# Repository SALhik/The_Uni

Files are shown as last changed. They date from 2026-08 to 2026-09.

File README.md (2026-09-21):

# The Uni Board
The uni-body split ortholinear keyboard for stenography, or the Uni for short. By Peter C Park. I used KiCad Nightly Release so the KiCad files are incompatible with older versions.

Buy it now at [StenoKeyboards.com](https://www.stenokeyboards.com/).

> **This checkout is a modified copy, not the upstream board.** The Pro Micro
> daughterboard has been replaced with an RP2040 module (Adafruit KB2040), which
> also moves the board to native USB-C. See
> [About this modification](#about-this-modification) for what changed, what was
> verified, and what was not. It is not affiliated with or endorsed by
> StenoKeyboards, and it is not any official Uni revision.

pcb
layout

## Product
If you are going DIY with this, here are the materials you need:
* The Uni PCB x 1 (diodes will come pre-assembled)
* Adafruit KB2040 x 1
* Switches x 28
* Keycaps x 28
* Willingness to solder x 1

If you want me to assemble here are the materials you need:
* money

## Microcontroller
This copy of the board is built around the **Adafruit KB2040** — an RP2040 module
in the Pro Micro form factor (33.02 x 17.78 mm) with 8 MB of QSPI flash and a
native USB-C connector.

Any module with the same 24-pin, 2.54 mm, 15.24 mm-row through-hole pattern will
physically fit, including the original Pro Micro and the Elite-C. **But the pin
functions are not interchangeable** — the schematic and silkscreen now name
RP2040 GPIOs, and pad 21 is treated as a 3.3 V regulator output rather than a
5 V rail. If you populate an AVR Pro Micro instead, the matrix still works
electrically, but use the original firmware pin names (see the table below).

## Switches
Nearly any switch is compatible with the v2. The board has a footprint that accomodates for mx, alps, and choc v1 style switches.

## Keycaps
The best keycaps to use are the OEM R3 keycaps with one of the rows inverted to reduce the gap in the middle.
I used to recommend 3d printing your caps but OEM R3 caps are better. There are other flat keycaps for mx style switches at pimpmykeyboard.com called f10 keycaps. There is also a slightly less flatter version called the G20 keycaps on their store and people have used them for steno.


## Soldering
All you have to solder are the switches and the KB2040 if you get the pcb with the diodes assembled. If not you'll have to solder the smd diodes yourself. Check the BOM file for the necessary materials.

The KB2040 mounts through-hole, in the same 24 holes the Pro Micro used. It
cannot be surface-mounted on this board — see [Castellated pads](#castellated-pads)
below.

`jlcpcb/assembly/` covers only the parts JLCPCB machine-assembles: the 28 SOD-123
diodes and the reset switch. The MCU module has never been listed there and still
isn't — you supply and solder it yourself, exactly as with the Pro Micro.

## About this modification

An independent modification of the upstream v2 hardware, moving it toward the
capabilities publicly described for later revisions. It was implemented from
scratch against public sources — Adafruit's own KB2040 design files for the
module, and the existing v2 KiCad files for everything else. No proprietary or
unreleased StenoKeyboards design files were used, referenced, or copied.

### What changed

| Area | Before | After |
| --- | --- | --- |
| MCU | Pro Micro (ATmega32U4) | Adafruit KB2040 (RP2040, 8 MB flash) |
| USB | micro-B | native USB-C |
| Logic rail | `+5V` | `+3V3` |
| Symbol | `keebio:ProMicro` | `uni-symbols:KB2040` |
| Footprint | `Keebio-Parts:ArduinoProMicro` | `uni-footprints:Adafruit_KB2040` |

Deliberately **unchanged**: key layout, switch matrix, diode topology, board
outline, mounting holes, and the MX/Alps/Choc hybrid switch footprint that gives
the board its spring-swap compatibility. The 24 through-hole pads keep their
exact original coordinates and drill sizes, and every *matrix* net keeps its pad
assignment, so no track was rerouted. One net name did change: the logic rail on
pad 21, `+5V` -> `+3V3`, per the table above. That rename is the only net-name
difference in the design, and the connectivity comparison normalises it. This
was verified by exporting the netlist before and after: 50 nets and 138 nodes in
both, with an identical connectivity graph.

### GPIO map

Every matrix net kept its physical pad, so this table is purely a renaming. The
"Pro Micro" column is the AVR pin the upstream QMK `config.h` refers to.

| Net | Pad | Pro Micro | KB2040 |
| --- | --- | --- | --- |
| `row0` | 20 | F4 | GP29 |
| `row1` | 14 | B2 | GP19 |
| `row2` | 13 | B6 | GP10 |
| `col0` | 19 | F5 | GP28 |
| `col1` | 18 | F6 | GP27 |
| `col2` | 17 | F7 | GP26 |
| `col3` | 16 | B1 | GP18 |
| `col4` | 15 | B3 | GP20 |
| `col5` | 12 | B5 | GP9 |
| `col6` | 11 | B4 | GP8 |
| `col7` | 10 | E6 | GP7 |
| `col8` | 9 | D7 | GP6 |
| `col9` | 8 | C6 | GP5 |
| `col10` | 7 | D4 | GP4 |

Matrix is 3 rows x 11 columns, `COL2ROW`, 28 keys. Pads 1, 2, 5 and 6 (GP0,
GP1, GP2, GP3) are unused, as they were on the Pro Micro. Pad 24 (`RAW`) is
unconnected; the KB2040 self-powers from USB through its own diode and
regulator.

**The firmware in `Firmware/` has not been ported** and still targets the
ATmega32U4. Adapting it is separate work.

### Silkscreen

The GPIO labels on the back are bare numbers (`4`, `29`) rather than `GP4`
style. The pads are on a 2.54 mm pitch and this board's setup enforces a 0.8 mm
minimum text height, at which four characters do not fit between adjacent pads.

### Castellated pads

The KB2040 has castellated edge pads for reflow mounting; **they are not placed
on this board, and the module must be through-hole soldered.** That is a layout
result rather than an assumption, but it comes from a PCB-layout and DRC
experiment in `unisplit_orthosteno.kicad_pcb`, not from a built board.
Castellated pads were added to the U1 footprint and shrunk down to 1.0 x 1.0 mm,
and at every size tried KiCad's DRC reported 10 net-to-net copper shorts against
the existing B.Cu matrix tracks, which already run through the channel where the
castellations would land — each castellation lands on top of its neighbour's
track. Nothing about solderability or reflow assembly was checked on hardware.
Fitting the castellations would require rerouting the matrix.

### Case and plate

The switch plate (`Case/switchplate/`) needed **no change**: switches are on
`F.Cu` and the module is on `B.Cu`, so they are on opposite faces, and the
module lands in a keyless channel that overlaps no cutout. Its 28 cutouts were
re-derived from the PCB switch coordinates and match exactly, at 14.00 x
14.00 mm. The back plate is likewise unchanged and still fully encloses the
module — the KB2040's onboard RESET and BOOT buttons are not externally
accessible, the same situation as the v2's own reset switch.

**The USB-C connector is wider than the micro-B it replaces.** Measured from
Adafruit's board file:

| | micro-B | USB-C | Delta |
| --- | --- | --- | --- |
| Connector width | 7.370 mm | 8.940 mm | +1.570 (about +0.79 per side) |
| Face inset from board edge | 0.145 mm | 0.462 mm | +0.317 deeper |

On the width alone this does **not** require a case change. The bezel in
`Case/3dp-full-case/full-case-bezels.kicad_pcb` already has a 17.462 mm notch in
its top edge (x 133.350 to 150.812), centred at x 142.081 — the module centre —
so an 8.940 mm connector clears it by about 4.26 mm a side. Only the width was
checked. The opening's height, whether a plug's overmold clears the recessed
board edge, and the printed `.stl` / `.FCStd` models were not measured.

### Fabrication outputs

`jlcpcb/gerber/` and `schematic.pdf` have been re-exported from the modified
design. The originals were plotted with KiCad 6.0.0 in 2022 and these with
KiCad 10.0.5, so the newer plotter re-renders mask and silkscreen and the file
diff is much larger than the design change. To separate the two, the *upstream*
board was exported with the same tool and settings and diffed against the new
export. Everything below is that comparison, not a claim about the raw diff:

| Layer | Change attributable to this modification |
| --- | --- |
| F.Cu, B.Cu | **no geometry change** — 40 differing lines per layer, all X2 netlist attributes: 38 `%TO.P%` pad names plus the 2 `%TO.N%` lines carrying the `+5V` -> `+3V3` rail rename; zero geometry ops |
| PTH, NPTH drill | **none** — 212 and 168 holes, byte-identical |
| Edge.Cuts | **none** — 24 ops, identical |
| F.Mask, B.Mask | **none** |
| F.Silkscreen, B.Silkscreen | changed, and confined to a 17.780 x 33.020 mm window — exactly the module outline |

`jlcpcb/assembly/` was deliberately **not** regenerated. No footprint moved (59
before, 59 after, zero position or rotation changes), and neither the BOM nor
the position file ever listed the MCU — they cover only the parts JLCPCB
machine-assembles.

The plate and back plate exports (`Case/switchplate/*/*.dxf`,
`Case/backplate/Gerbers/`) are also unchanged, because neither of those boards
was modified.

### Not verified

Stated so you know where to double-check rather than trust this document:

* **No physical build has been made.** Everything here is from file analysis.
* **No component heights were confirmed.** KB2040 PCB thickness, USB-C
  receptacle height, and whether a USB-C plug's overmold clears the recessed
  board edge are all unknown here. Later revisions are *reported* to use 5 mm
  screws and 9 mm standoffs against v2/v3's 4 mm and 4 mm; that figure is
  repeated here as hearsay and was **not** derived from these files. Confirm
  against the real parts before ordering hardware.
* **Nothing has been test-fabricated.** The gerbers are regenerated and were
  checked against a same-tool export of the upstream board, but no board house
  has run them and no panel has been built from them.
* **The exports come from a newer KiCad than the design file.** The board is
  still in KiCad 6 format and was plotted with KiCad 10.0.5. That is normal and
  the geometry was verified, but if you have KiCad 6 to hand, re-plotting there
  would keep the toolchain consistent.

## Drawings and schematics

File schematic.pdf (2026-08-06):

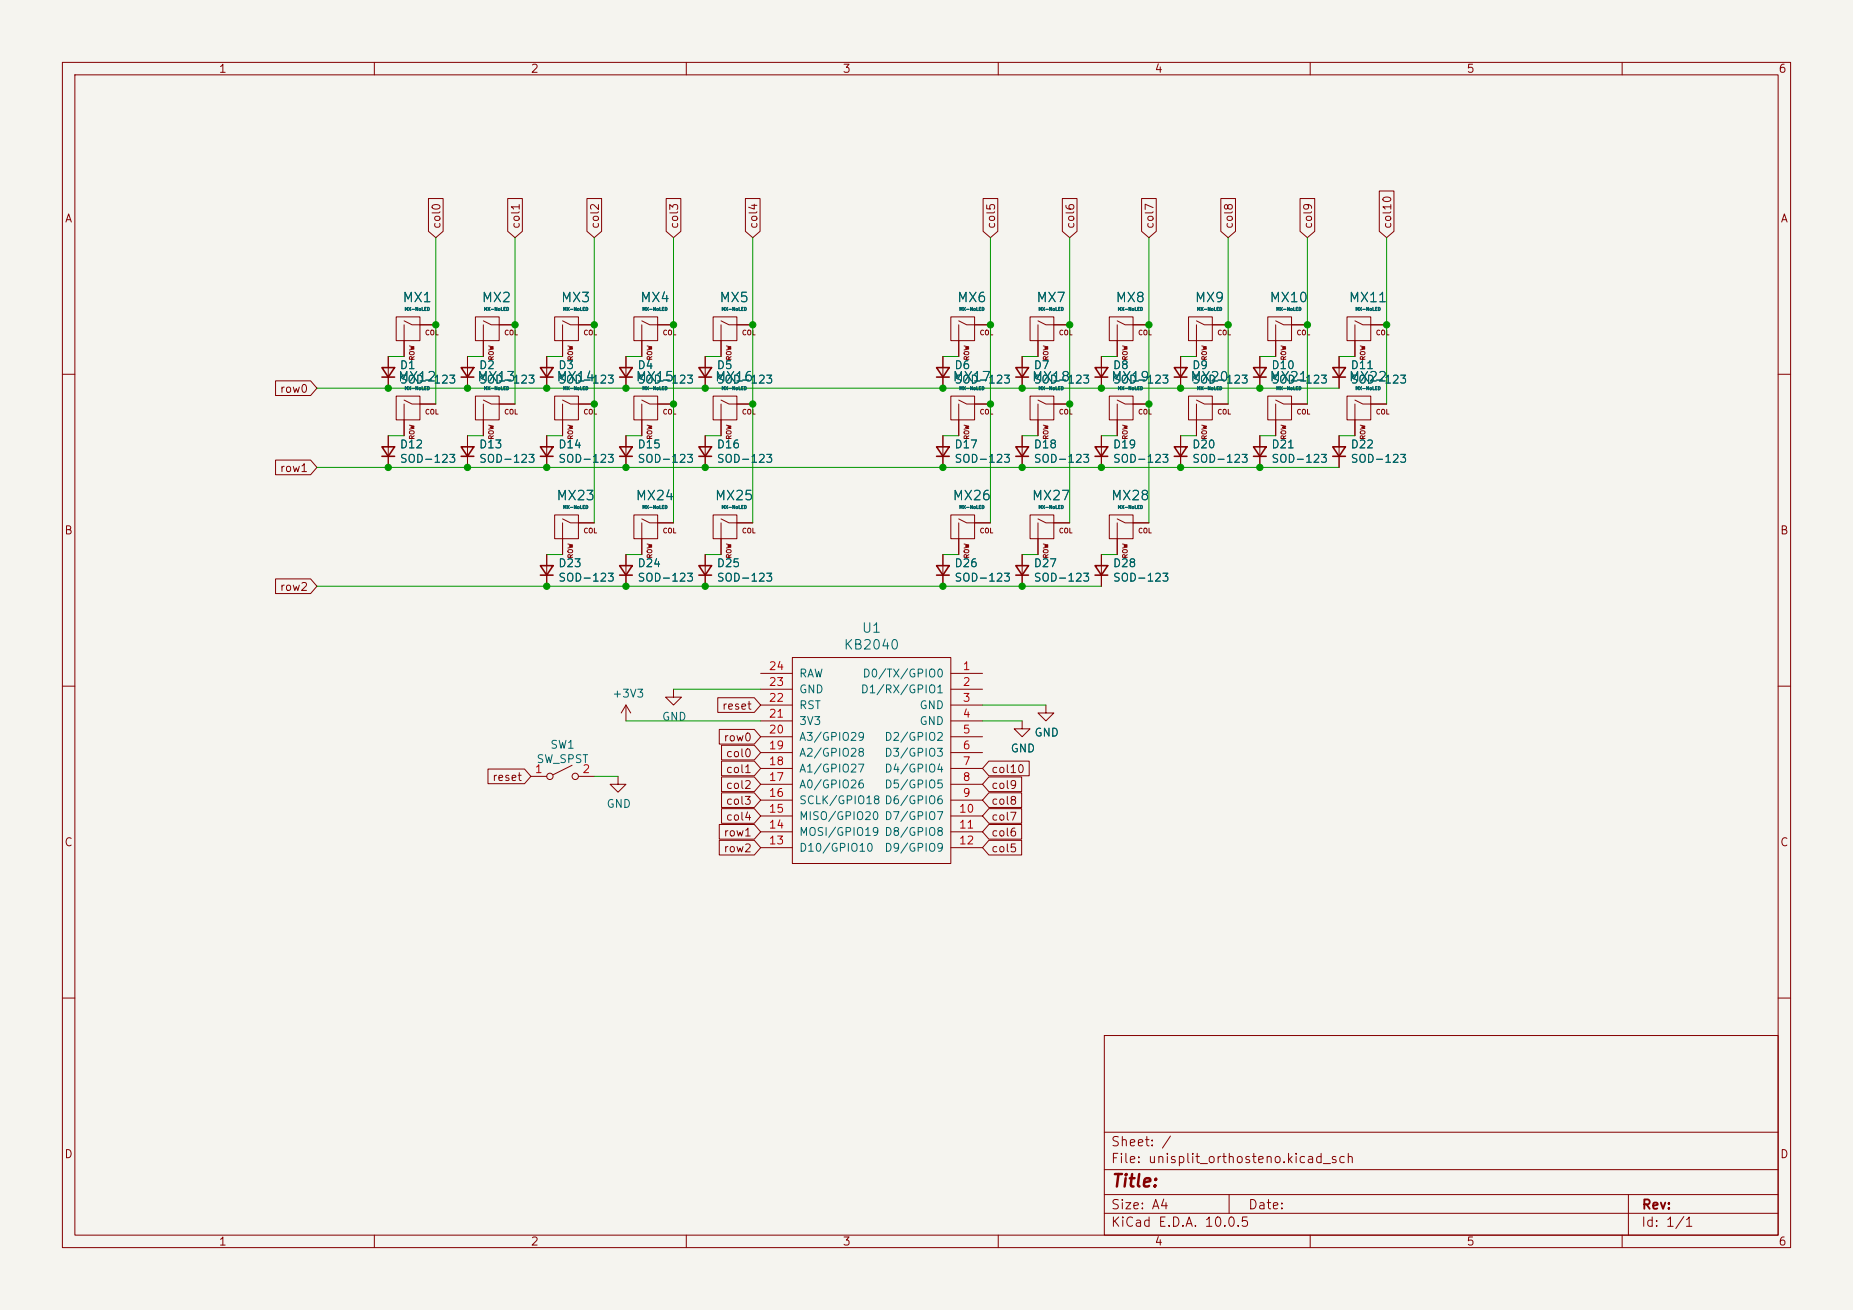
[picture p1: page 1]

COL MX1
MX-NoLED D2 MX13 SOD-123 MX-NoLED D13

COL MX2
MX-NoLED D1 MX12 SOD-123 MX-NoLED D12

Size: A4 | Rev:
KiCad E.D.A. 10.0.5 | Id: 1/1

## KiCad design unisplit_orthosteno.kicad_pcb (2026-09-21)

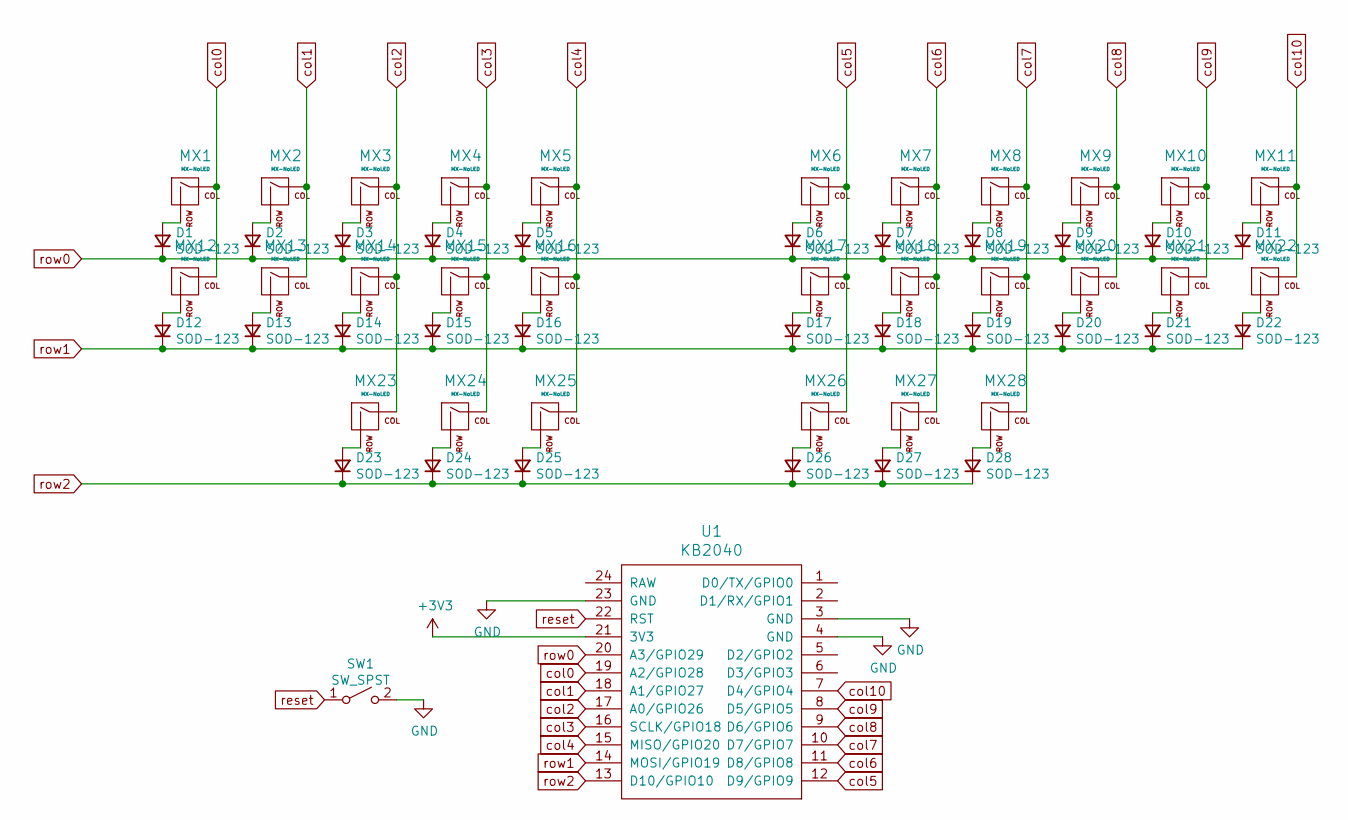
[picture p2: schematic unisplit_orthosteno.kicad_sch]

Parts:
D1, D2, D3, D4, D5, D6, D7, D8, D9, D10, D11, D12, D13, D15, D16, D17, D18, D19, D20, D21, D22, D23, D24, D25, D26, D27, D28: SOD-123; D_SOD123; LCSC C81598
D14: SOD-123; D_SOD123
MX1, MX2, MX3, MX4, MX5, MX6, MX7, MX8, MX9, MX10, MX11, MX12, MX13, MX14, MX15, MX16, MX17, MX18, MX19, MX20, MX21, MX22, MX23, MX24, MX25, MX26, MX27, MX28: MX-NoLED; MX-Alps-Choc-1U-NoLED
SW1: SW_SPST; SW_SPST_TL3342
U1: KB2040; Adafruit_KB2040

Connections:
+3V3: U1.21 (3V3)
GND: SW1.2 (B), U1.3 (GND), U1.4 (GND), U1.23 (GND)
unnamed: D1.2 (A), MX1.2 (ROW)
unnamed: D2.2 (A), MX2.2 (ROW)
unnamed: D3.2 (A), MX3.2 (ROW)
unnamed: D4.2 (A), MX4.2 (ROW)
unnamed: D5.2 (A), MX5.2 (ROW)
unnamed: D6.2 (A), MX6.2 (ROW)
unnamed: D7.2 (A), MX7.2 (ROW)
unnamed: D8.2 (A), MX8.2 (ROW)
unnamed: D9.2 (A), MX9.2 (ROW)
unnamed: D10.2 (A), MX10.2 (ROW)
unnamed: D11.2 (A), MX11.2 (ROW)
unnamed: D12.2 (A), MX12.2 (ROW)
unnamed: D13.2 (A), MX13.2 (ROW)
unnamed: D14.2 (A), MX14.2 (ROW)
unnamed: D15.2 (A), MX15.2 (ROW)
unnamed: D16.2 (A), MX16.2 (ROW)
unnamed: D17.2 (A), MX17.2 (ROW)
unnamed: D18.2 (A), MX18.2 (ROW)
unnamed: D19.2 (A), MX19.2 (ROW)
unnamed: D20.2 (A), MX20.2 (ROW)
unnamed: D21.2 (A), MX21.2 (ROW)
unnamed: D22.2 (A), MX22.2 (ROW)
unnamed: D23.2 (A), MX23.2 (ROW)
unnamed: D24.2 (A), MX24.2 (ROW)
unnamed: D25.2 (A), MX25.2 (ROW)
unnamed: D26.2 (A), MX26.2 (ROW)
unnamed: D27.2 (A), MX27.2 (ROW)
unnamed: D28.2 (A), MX28.2 (ROW)
col0: MX1.1 (COL), MX12.1 (COL), U1.19 (A2/GPIO28)
col1: MX2.1 (COL), MX13.1 (COL), U1.18 (A1/GPIO27)
col2: MX3.1 (COL), MX14.1 (COL), MX23.1 (COL), U1.17 (A0/GPIO26)
col3: MX4.1 (COL), MX15.1 (COL), MX24.1 (COL), U1.16 (SCLK/GPIO18)
col4: MX5.1 (COL), MX16.1 (COL), MX25.1 (COL), U1.15 (MISO/GPIO20)
col5: MX6.1 (COL), MX17.1 (COL), MX26.1 (COL), U1.12 (D9/GPIO9)
col6: MX7.1 (COL), MX18.1 (COL), MX27.1 (COL), U1.11 (D8/GPIO8)
col7: MX8.1 (COL), MX19.1 (COL), MX28.1 (COL), U1.10 (D7/GPIO7)
col8: MX9.1 (COL), MX20.1 (COL), U1.9 (D6/GPIO6)
col9: MX10.1 (COL), MX21.1 (COL), U1.8 (D5/GPIO5)
col10: MX11.1 (COL), MX22.1 (COL), U1.7 (D4/GPIO4)
reset: SW1.1 (A), U1.22 (RST)
row0: D1.1 (K), D2.1 (K), D3.1 (K), D4.1 (K), D5.1 (K), D6.1 (K), D7.1 (K), D8.1 (K), D9.1 (K), D10.1 (K), D11.1 (K), U1.20 (A3/GPIO29)
row1: D12.1 (K), D13.1 (K), D14.1 (K), D15.1 (K), D16.1 (K), D17.1 (K), D18.1 (K), D19.1 (K), D20.1 (K), D21.1 (K), D22.1 (K), U1.14 (MOSI/GPIO19)
row2: D23.1 (K), D24.1 (K), D25.1 (K), D26.1 (K), D27.1 (K), D28.1 (K), U1.13 (D10/GPIO10)

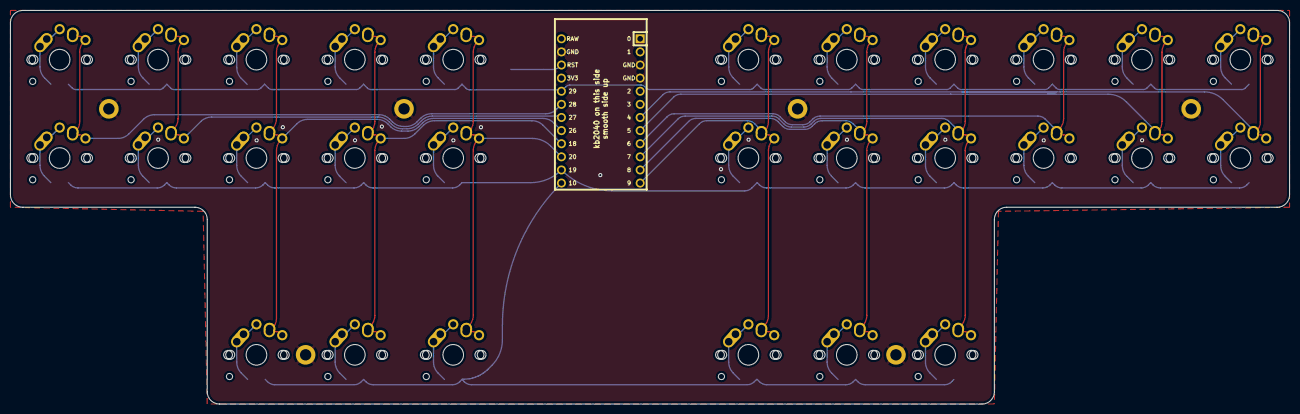
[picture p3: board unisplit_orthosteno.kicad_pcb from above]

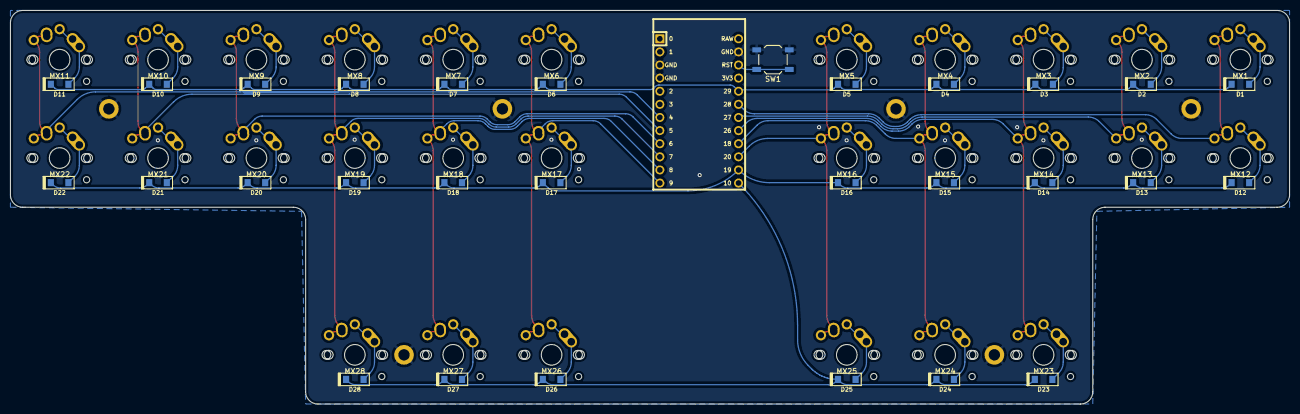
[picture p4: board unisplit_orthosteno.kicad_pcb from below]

Board: 2 copper layers, 247.6 x 76.2 mm, 58 parts (30 on the bottom side), 44 nets.

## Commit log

2026-08-04 feat(mcu): add KB2040 symbol and footprint libraries
    Adds an Adafruit KB2040 symbol and footprint, derived from Adafruit's
    published EagleCAD design files for the module rather than from any
    StenoKeyboards source. The footprint reuses the Pro Micro's 24
    through-hole pads verbatim (position, 1.7526 mm pad, 1.0922 mm drill) so
    that swapping it in requires no rerouting.
    Castellated edge pads are deliberately absent. Existing B.Cu matrix
    tracks run through the channel where they would land, and pads at every
    size tried, down to 1.0 x 1.0 mm, short 10 net pairs against those
    tracks. Reflow mounting would require rerouting the matrix.
    Also adds the project fp-lib-table and sym-lib-table, which t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
2026-08-04 feat(mcu): swap Pro Micro for KB2040 in the schematic
    Repoints U1 at uni-symbols:KB2040 and renames pins to their RP2040
    functions. Pin numbers and pin coordinates are unchanged, so every wire,
    junction and global label stays attached; the matrix netlist is
    untouched.
    Renames the +5V rail to +3V3. KB2040 pad 21 is a 3.3 V regulator output,
    not a 5 V rail, and is now typed power_out accordingly. The rail drives
    nothing but the passive diode matrix, so this is an accurate relabelling
    rather than a circuit change.
    Pad 24 (RAW) is now typed power_in instead of input. It remains
    unconnected, as on the Pro Micro; per Adafruit's schematic the module
    self-powers from USB through D1 into regulator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
    [unisplit_orthosteno.kicad_sch]
2026-08-04 feat(mcu): swap Pro Micro footprint for KB2040 on the PCB
    Replaces the Keebio-Parts:ArduinoProMicro footprint at U1 with
    uni-footprints:Adafruit_KB2040. All 24 pads keep their exact
    coordinates, sizes, drills, nets and tstamps, so no track moved.
    Silkscreen labels become RP2040 GPIO numbers; they are bare numerals
    because board setup enforces a 0.8 mm minimum text height, at which
    four characters do not fit on the 2.54 mm pad pitch.
    Adds an F/B courtyard, which the Pro Micro footprint lacked, and
    replaces the micro-USB outline on Dwgs.User with the USB-C mechanical
    envelope measured from Adafruit's board file. The connector is 1.570 mm
    wider and sits 0.317 mm further inside the board edge,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
    [unisplit_orthosteno.kicad_pcb]
2026-08-04 fix(case): repoint plate library tables at the repository
    Both plate projects referenced a previous author's home directory, so
    neither opened with its footprints resolved. Replaces the absolute paths
    with ${KIPRJMOD}-relative ones.
    Switch plate DRC 134 -> 106; every geometry violation is unchanged, only
    the unresolved-library warnings clear. Back plate now resolves its logo
    footprints and reports 11 warnings, 0 errors.
    Neither .kicad_pcb is modified. The switch plate needs no geometry
    change for the MCU swap: switches are on F.Cu and the module on B.Cu, so
    they sit on opposite faces, and the module lands in a keyless channel
    overlapping no cutout. Its 28 cutouts were re-derived from the P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
2026-08-04 docs: document the KB2040 modification
    Rewrites the Pro-Micro-specific sections and adds an "About this
    modification" section framing this as an independent reimplementation
    built from Adafruit's published module files and the existing v2 KiCad
    sources, not from any StenoKeyboards design files.
    Includes the verified pad-to-GPIO map. Each of the 14 matrix nets kept
    its physical pad, and each old Pro Micro pin name carries exactly the
    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
2026-08-06 chore(fab): regenerate gerbers and drill files for the KB2040
    The committed set was plotted with KiCad 6.0.0 in 2022; only KiCad 10.0.5 is
    available here, so the newer plotter re-renders mask and silkscreen and the
    raw diff is far larger than the design change.
    To isolate the design change, the upstream board was exported with identical
    tool and settings and diffed against this export:
    F.Cu, B.Cu no geometry change; 38 differing lines per layer, all
    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
    [unisplit_orthosteno-B_Cu.gbl, unisplit_orthosteno-B_Mask.gbs, unisplit_orthosteno-B_Silkscreen.gbo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]
2026-08-06 docs: regenerate schematic PDF for the KB2040
    Re-plotted from the modified schematic. Verified against a same-source SVG
    export: KB2040 and +3V3 present, no ProMicro or +5V references remain.
2026-08-06 docs: record what the regenerated exports cover, correct case claim
    Adds a "Fabrication outputs" section stating which layers actually changed and
    why jlcpcb/assembly/, the plate DXFs and the back plate gerbers were left
    alone: no footprint moved (59 before, 59 after) and neither assembly file ever
    listed the MCU.
    Also corrects an unsupported claim. The README previously said the 3D-printed
    case USB opening "must be enlarged", inferred from connector widths rather than
    measured. The bezel already has a 17.462 mm notch centred at x 142.081, the
    module centre, so the 8.940 mm USB-C clears by about 4.26 mm a side. The claim
    is now scoped to width only; opening height and the STL/FCStd models r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
2026-09-21 fix(pcb): name the KB2040 logic rail +3V3 to match the schematic
    The schematic drives U1 pad 21 from a +3V3 power symbol, and the pad already
    carries pinfunction "3V3" / pintype "power_out", but the board file still
    declared and referenced net 45 as "+5V" - the Pro Micro name it inherited. The
    generated gerbers inherited it too, emitting %TO.N,+5V*% for that pad.
    Net 45 has a single node (U1 pad 21) and no tracks, so this is a rename with no
    connectivity change. Verified against a netlist export of the schematic: the
    only PCB/schematic net-name mismatch on a PR-touched node was this one, and DRC
    is unchanged at 230 violations with 0 unconnected items before and after.
    Gerbers and drill fil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
    [unisplit_orthosteno-B_Cu.gbl, unisplit_orthosteno-B_Mask.gbs, unisplit_orthosteno-B_Silkscreen.gbo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]
2026-09-21 docs: scope the net claim and name the castellated-pad method
    Three accuracy fixes to README claims:
    The "pads keep their exact original coordinates, drill sizes and nets" sentence
    overstated the case - the logic rail on pad 21 is renamed +5V -> +3V3, as the
    table three lines above already says. Scope the claim to the matrix nets and
    name the one exception.
    The castellated-pad section said "this was tested", which reads as a hardware
    result next to a "no physical build has been made" disclaimer further down. It
    was a PCB-layout and DRC experiment; say so, name the file and the tracks it
    ran against, and drop the implied solderability judgement.
    Fix the opening line's KiCad capitalisation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
